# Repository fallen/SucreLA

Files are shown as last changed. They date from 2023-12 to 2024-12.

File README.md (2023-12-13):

# SucréLA

## Building

The project Python's dependencies are handled using Pipenv.
However, you must install [nextpnr-ecp5](https://github.com/YosysHQ/nextpnr) and [Yosys](https://github.com/YosysHQ/yosys) if you wish to build the
projet from source.

```
pipenv install --ignore-pipfile
pipenv run python3 ./sucrela.py --build
```

## Flashing the OrangeCrab

```
pipenv run python3 ./sucrela.py --load
```

## Runing simulation

```
pipenv run python3 ./sucrela.py --sim
```

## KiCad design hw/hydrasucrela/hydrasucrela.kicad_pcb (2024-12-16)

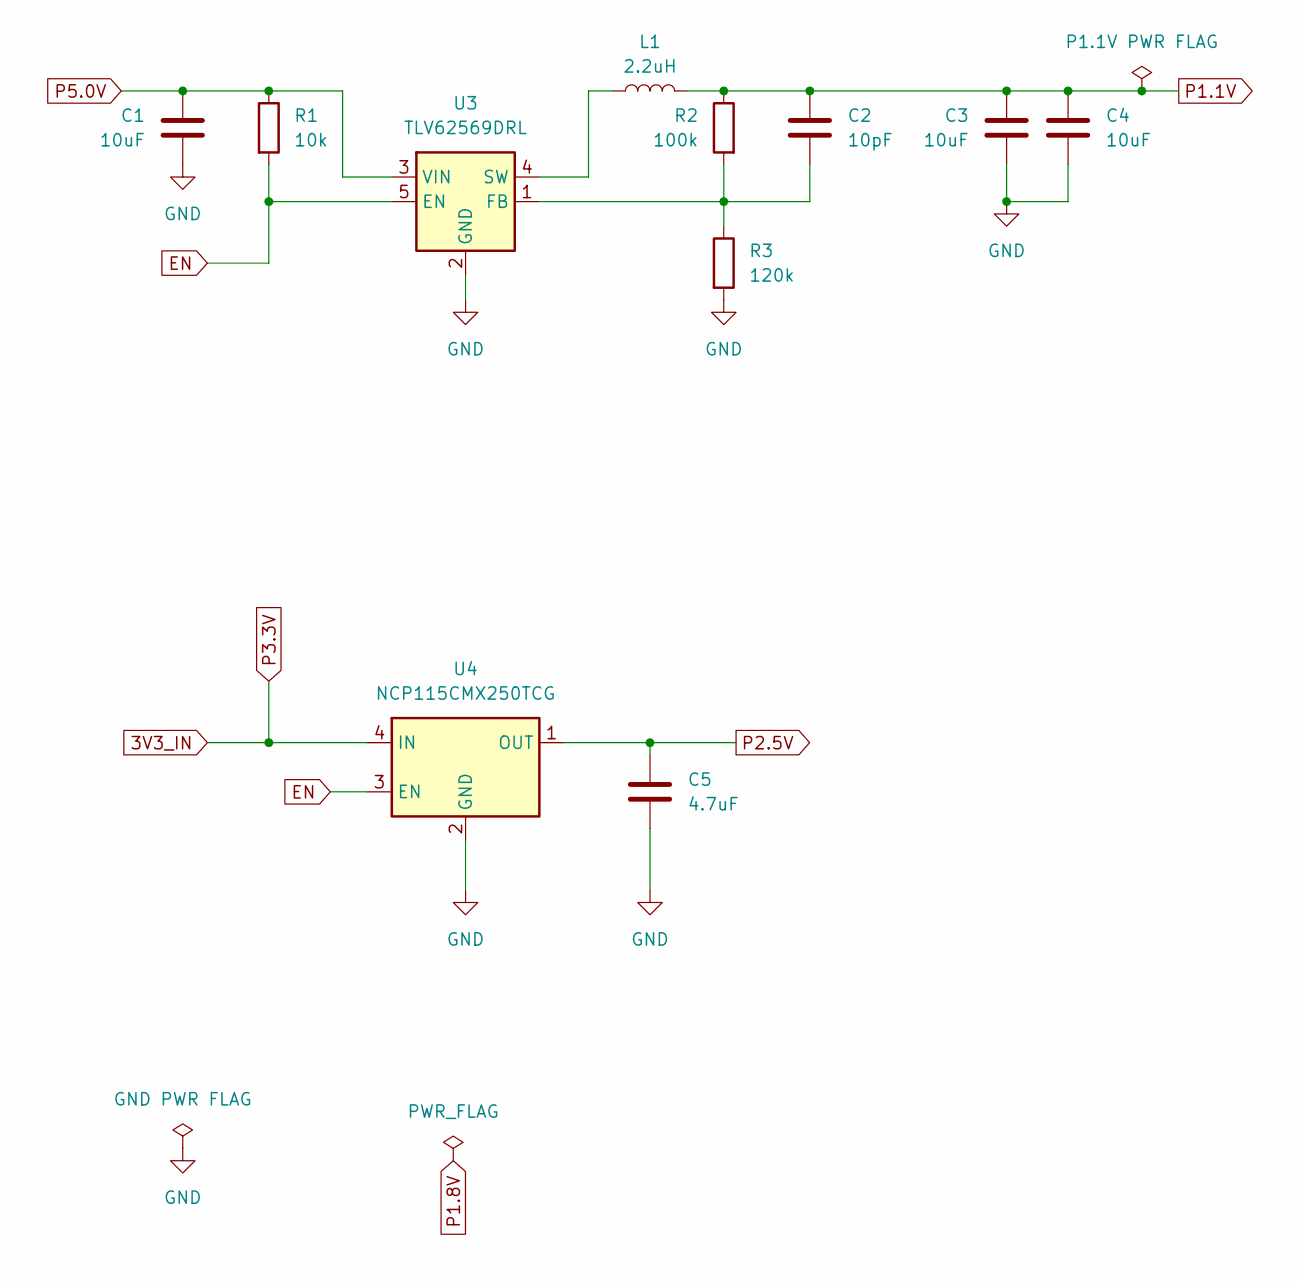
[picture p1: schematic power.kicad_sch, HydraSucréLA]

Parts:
C1, C3, C4: 10uF; C_0603_1608Metric_Pad1.08x0.95mm_HandSolder
C2: 10pF; C_0603_1608Metric_Pad1.08x0.95mm_HandSolder
C5: 4.7uF; C_0603_1608Metric_Pad1.08x0.95mm_HandSolder
L1: 2.2uH; L_0603_1608Metric_Pad1.05x0.95mm_HandSolder
R1: 10k; R_0603_1608Metric_Pad0.98x0.95mm_HandSolder
R2: 100k; R_0603_1608Metric_Pad0.98x0.95mm_HandSolder
R3: 120k; R_0603_1608Metric_Pad0.98x0.95mm_HandSolder
U3: TLV62569DRL; SOT-563
U4: NCP115CMX250TCG; OnSemi_XDFN4-1EP_1.0x1.0mm_EP0.52x0.52mm

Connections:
3V3_IN: U4.4 (IN); also elsewhere on the board
EN: R1.2, U3.5 (EN), U4.3 (EN)
GND: C1.2, C3.1, C4.1, C5.2, R3.2, U3.2 (GND), U4.2 (GND), U4.5 (GND); also elsewhere on the board
unnamed: C2.1, R2.2, R3.1, U3.1 (FB)
unnamed: L1.1, U3.4 (SW)
P1.1V: C2.2, C3.2, C4.2, L1.2, R2.1; also elsewhere on the board
P2.5V: C5.1, U4.1 (OUT); also elsewhere on the board
P5.0V: C1.1, R1.1, U3.3 (VIN); also elsewhere on the board

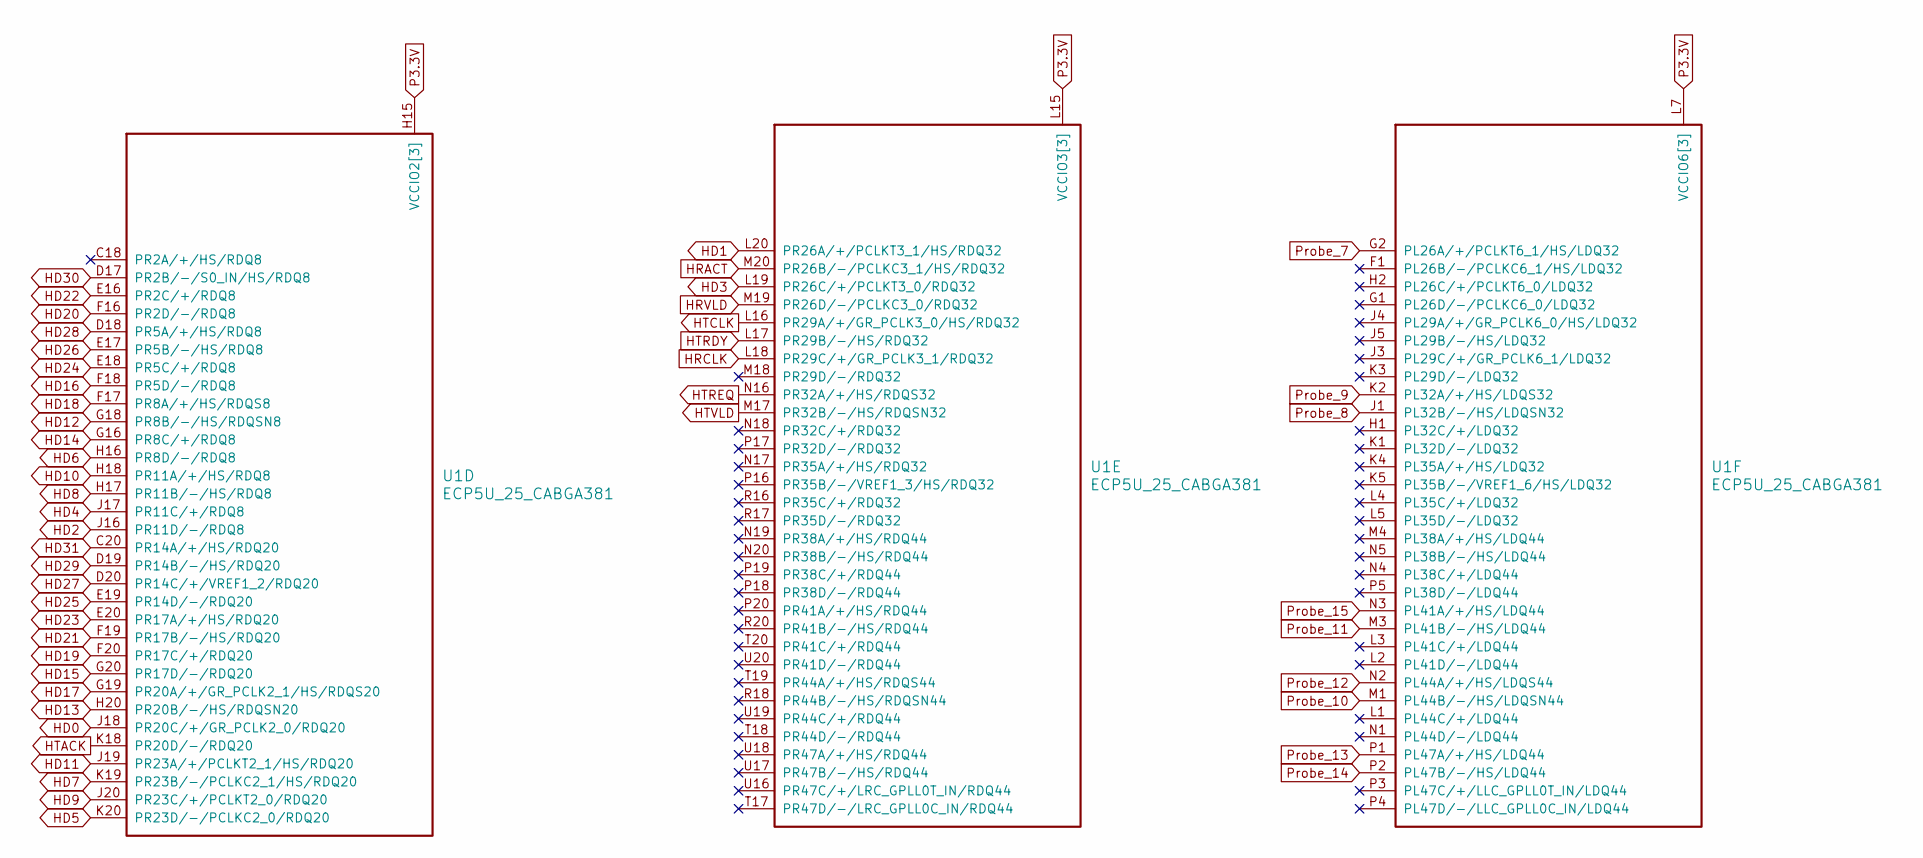
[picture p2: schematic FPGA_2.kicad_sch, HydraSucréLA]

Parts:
U1: ECP5U_25_CABGA381; Lattice_caBGA-381_17.0x17.0mm_Layout20x20_P0.8mm_Ball0.4mm_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

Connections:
3V3_IN: U1.H14 (VCCIO2[3]), U1.H15 (VCCIO2[3]), U1.J15 (VCCIO2[3]), U1.L6 (VCCIO6[3]), U1.L7 (VCCIO6[3]), U1.L14 (VCCIO3[3]), U1.L15 (VCCIO3[3]), U1.M6 (VCCIO6[3]), U1.M15 (VCCIO3[3]); also elsewhere on the board
HD0: U1.J18 (PR20C/+/GR_PCLK2_0/RDQ20); also elsewhere on the board
HD1: U1.L20 (PR26A/+/PCLKT3_1/HS/RDQ32); also elsewhere on the board
HD2: U1.J16 (PR11D/-/RDQ8); also elsewhere on the board
HD3: U1.L19 (PR26C/+/PCLKT3_0/RDQ32); also elsewhere on the board
HD4: U1.J17 (PR11C/+/RDQ8); also elsewhere on the board
HD5: U1.K20 (PR23D/-/PCLKC2_0/RDQ20); also elsewhere on the board
HD6: U1.H16 (PR8D/-/RDQ8); also elsewhere on the board
HD7: U1.K19 (PR23B/-/PCLKC2_1/HS/RDQ20); also elsewhere on the board
HD8: U1.H17 (PR11B/-/HS/RDQ8); also elsewhere on the board
HD9: U1.J20 (PR23C/+/PCLKT2_0/RDQ20); also elsewhere on the board
HD10: U1.H18 (PR11A/+/HS/RDQ8); also elsewhere on the board
HD11: U1.J19 (PR23A/+/PCLKT2_1/HS/RDQ20); also elsewhere on the board
HD12: U1.G18 (PR8B/-/HS/RDQSN8); also elsewhere on the board
HD13: U1.H20 (PR20B/-/HS/RDQSN20); also elsewhere on the board
HD14: U1.G16 (PR8C/+/RDQ8); also elsewhere on the board
HD15: U1.G20 (PR17D/-/RDQ20); also elsewhere on the board
HD16: U1.F18 (PR5D/-/RDQ8); also elsewhere on the board
HD17: U1.G19 (PR20A/+/GR_PCLK2_1/HS/RDQS20); also elsewhere on the board
HD18: U1.F17 (PR8A/+/HS/RDQS8); also elsewhere on the board
HD19: U1.F20 (PR17C/+/RDQ20); also elsewhere on the board
HD20: U1.F16 (PR2D/-/RDQ8); also elsewhere on the board
HD21: U1.F19 (PR17B/-/HS/RDQ20); also elsewhere on the board
HD22: U1.E16 (PR2C/+/RDQ8); also elsewhere on the board
HD23: U1.E20 (PR17A/+/HS/RDQ20); also elsewhere on the board
HD24: U1.E18 (PR5C/+/RDQ8); also elsewhere on the board
HD25: U1.E19 (PR14D/-/RDQ20); also elsewhere on the board
HD26: U1.E17 (PR5B/-/HS/RDQ8); also elsewhere on the board
HD27: U1.D20 (PR14C/+/VREF1_2/RDQ20); also elsewhere on the board
HD28: U1.D18 (PR5A/+/HS/RDQ8); also elsewhere on the board
HD29: U1.D19 (PR14B/-/HS/RDQ20); also elsewhere on the board
HD30: U1.D17 (PR2B/-/S0_IN/HS/RDQ8); also elsewhere on the board
HD31: U1.C20 (PR14A/+/HS/RDQ20); also elsewhere on the board
HRACT: U1.M20 (PR26B/-/PCLKC3_1/HS/RDQ32); also elsewhere on the board
HRCLK: U1.L18 (PR29C/+/GR_PCLK3_1/RDQ32); also elsewhere on the board
HRVLD: U1.M19 (PR26D/-/PCLKC3_0/RDQ32); also elsewhere on the board
HTACK: U1.K18 (PR20D/-/RDQ20); also elsewhere on the board
HTCLK: U1.L16 (PR29A/+/GR_PCLK3_0/HS/RDQ32); also elsewhere on the board
HTRDY: U1.L17 (PR29B/-/HS/RDQ32); also elsewhere on the board
HTREQ: U1.N16 (PR32A/+/HS/RDQS32); also elsewhere on the board
HTVLD: U1.M17 (PR32B/-/HS/RDQSN32); also elsewhere on the board
Probe_7: U1.G2 (PL26A/+/PCLKT6_1/HS/LDQ32); also elsewhere on the board
Probe_8: U1.J1 (PL32B/-/HS/LDQSN32); also elsewhere on the board
Probe_9: U1.K2 (PL32A/+/HS/LDQS32); also elsewhere on the board
Probe_10: U1.M1 (PL44B/-/HS/LDQSN44); also elsewhere on the board
Probe_11: U1.M3 (PL41B/-/HS/LDQ44); also elsewhere on the board
Probe_12: U1.N2 (PL44A/+/HS/LDQS44); also elsewhere on the board
Probe_13: U1.P1 (PL47A/+/HS/LDQ44); also elsewhere on the board
Probe_14: U1.P2 (PL47B/-/HS/LDQ44); also elsewhere on the board
Probe_15: U1.N3 (PL41A/+/HS/LDQ44); also elsewhere on the board

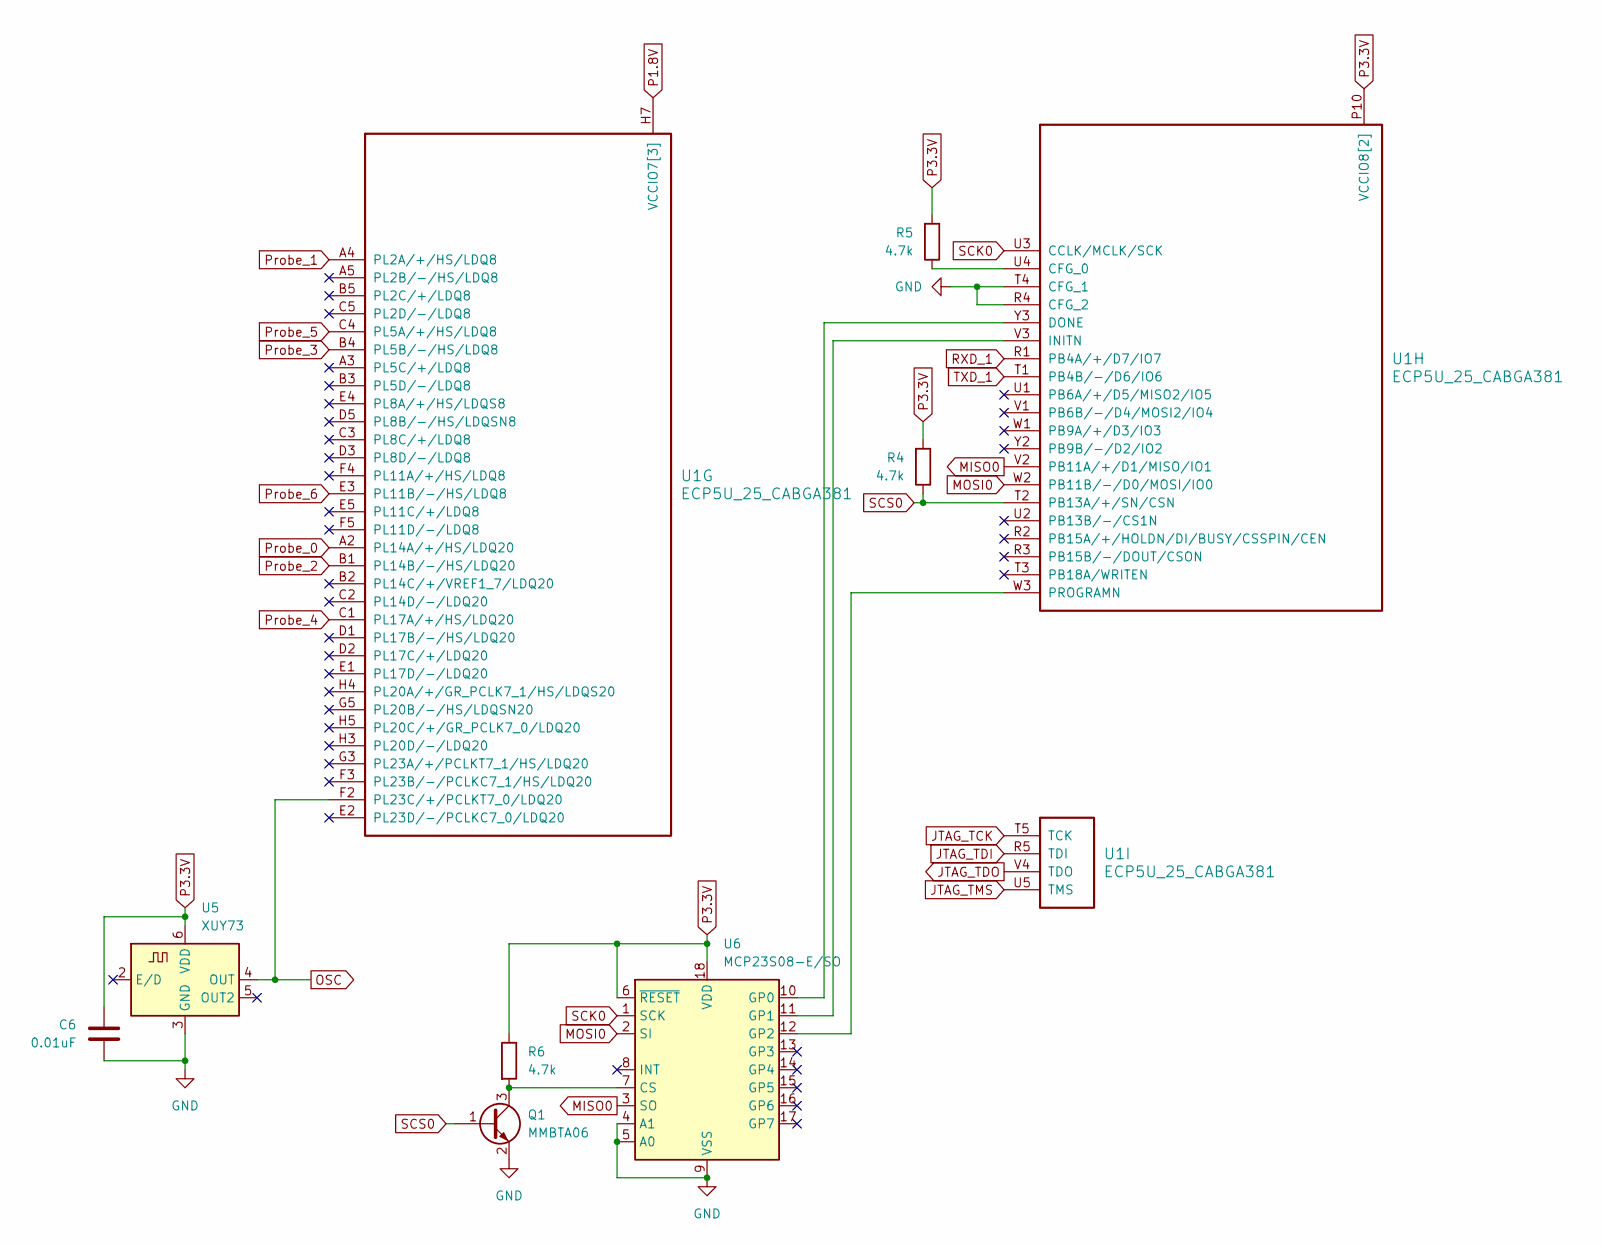
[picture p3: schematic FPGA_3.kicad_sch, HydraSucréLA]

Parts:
C6: 0.01uF; C_0603_1608Metric_Pad1.08x0.95mm_HandSolder
Q1: MMBTA06; SOT-23
R4, R5, R6: 4.7k; R_0603_1608Metric_Pad0.98x0.95mm_HandSolder
U1: ECP5U_25_CABGA381; Lattice_caBGA-381_17.0x17.0mm_Layout20x20_P0.8mm_Ball0.4mm_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
U5: XUY73; Oscillator_SMD_IDT_JU6-6_7.0x5.0mm_P2.54mm
U6: MCP23S08-E/SO; SOIC-18W_7.5x11.6mm_P1.27mm

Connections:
3V3_IN: C6.1, R4.2, R5.2, R6.1, U1.P9 (VCCIO8[2]), U1.P10 (VCCIO8[2]), U5.6 (VDD), U6.6 (~RESET), U6.18 (VDD); also elsewhere on the board
GND: C6.2, Q1.2 (E), U1.R4 (CFG_2), U1.T4 (CFG_1), U5.3 (GND), U6.4 (A1), U6.5 (A0), U6.9 (VSS); also elsewhere on the board
JTAG_TCK: U1.T5 (TCK); also elsewhere on the board
JTAG_TDI: U1.R5 (TDI); also elsewhere on the board
JTAG_TDO: U1.V4 (TDO); also elsewhere on the board
JTAG_TMS: U1.U5 (TMS); also elsewhere on the board
MISO0: U1.V2 (PB11A/+/D1/MISO/IO1), U6.3 (SO); also elsewhere on the board
MOSI0: U1.W2 (PB11B/-/D0/MOSI/IO0), U6.2 (SI); also elsewhere on the board
unnamed: Q1.3 (C), R6.2, U6.7 (CS)
unnamed: R5.1, U1.U4 (CFG_0)
unnamed: U1.Y3 (DONE), U6.10 (GP0)
unnamed: U1.V3 (INITN), U6.11 (GP1)
unnamed: U1.W3 (PROGRAMN), U6.12 (GP2)
OSC: U1.F2 (PL23C/+/PCLKT7_0/LDQ20), U5.4 (OUT)
P1.8V: U1.H6 (VCCIO7[3]), U1.H7 (VCCIO7[3]), U1.J6 (VCCIO7[3])
Probe_0: U1.A2 (PL14A/+/HS/LDQ20); also elsewhere on the board
Probe_1: U1.A4 (PL2A/+/HS/LDQ8); also elsewhere on the board
Probe_2: U1.B1 (PL14B/-/HS/LDQ20); also elsewhere on the board
Probe_3: U1.B4 (PL5B/-/HS/LDQ8); also elsewhere on the board
Probe_4: U1.C1 (PL17A/+/HS/LDQ20); also elsewhere on the board
Probe_5: U1.C4 (PL5A/+/HS/LDQ8); also elsewhere on the board
Probe_6: U1.E3 (PL11B/-/HS/LDQ8); also elsewhere on the board
RXD_1: U1.R1 (PB4A/+/D7/IO7); also elsewhere on the board
SCK0: U1.U3 (CCLK/MCLK/SCK), U6.1 (SCK); also elsewhere on the board
SCS0: Q1.1 (B), R4.1, U1.T2 (PB13A/+/SN/CSN); also elsewhere on the board
TXD_1: U1.T1 (PB4B/-/D6/IO6); also elsewhere on the board

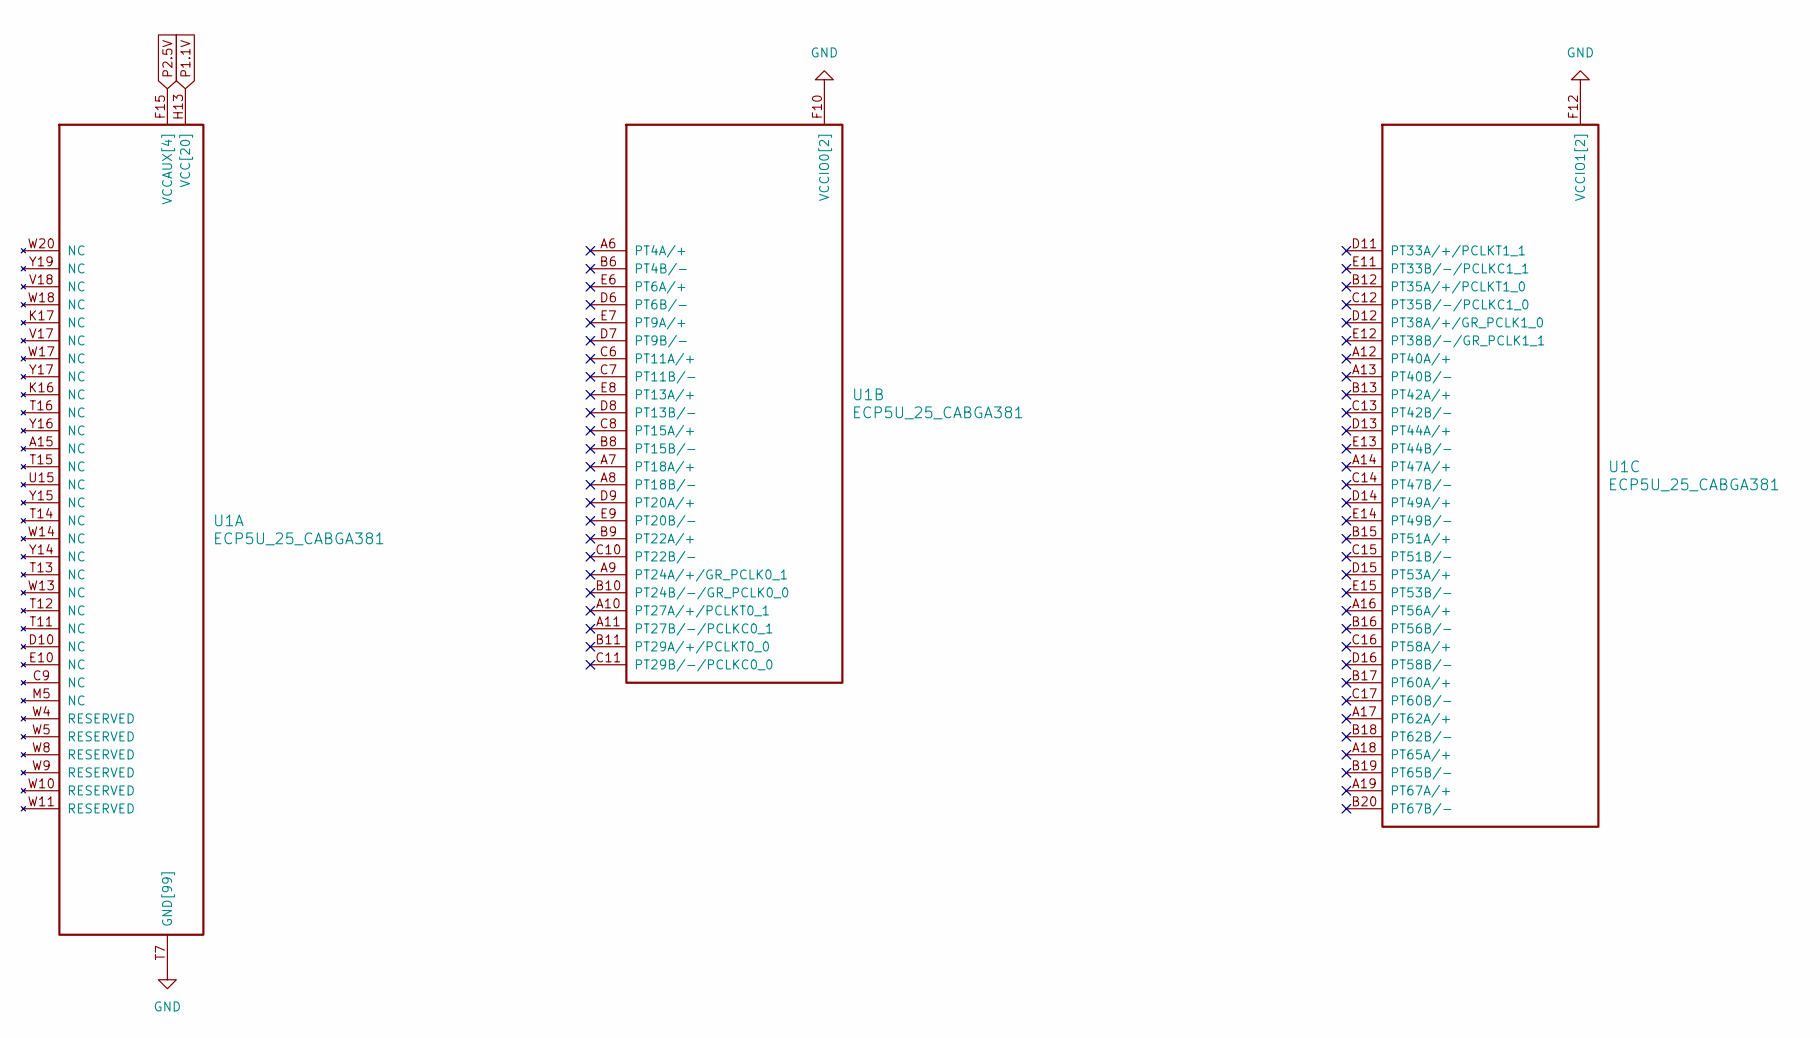
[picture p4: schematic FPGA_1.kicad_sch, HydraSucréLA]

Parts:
U1: ECP5U_25_CABGA381; Lattice_caBGA-381_17.0x17.0mm_Layout20x20_P0.8mm_Ball0.4mm_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

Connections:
GND: U1.B7 (GND[99]), U1.B14 (GND[99]), U1.C19 (GND[99]), U1.D4 (GND[99]), U1.F7 (GND[99]), U1.F8 (GND[99]), U1.F9 (VCCIO0[2]), U1.F10 (VCCIO0[2]), U1.F11 (VCCIO1[2]), U1.F12 (VCCIO1[2]), U1.F13 (GND[99]), U1.F14 (GND[99]), U1.G4 (GND[99]), U1.G6 (GND[99]), U1.G7 (GND[99]), U1.G8 (GND[99]), U1.G9 (GND[99]), U1.G10 (GND[99]), U1.G11 (GND[99]), U1.G12 (GND[99]), U1.G13 (GND[99]), U1.G14 (GND[99]), U1.G15 (GND[99]), U1.G17 (GND[99]), U1.H19 (GND[99]), U1.J2 (GND[99]), U1.J7 (GND[99]), U1.J9 (GND[99]), U1.J10 (GND[99]), U1.J11 (GND[99]), U1.J12 (GND[99]), U1.J14 (GND[99]), U1.K6 (GND[99]), U1.K7 (GND[99]), U1.K9 (GND[99]), U1.K10 (GND[99]), U1.K11 (GND[99]), U1.K12 (GND[99]), U1.K14 (GND[99]), U1.K15 (GND[99]), U1.L9 (GND[99]), U1.L10 (GND[99]), U1.L11 (GND[99]), U1.L12 (GND[99]), U1.M2 (GND[99]), U1.M7 (GND[99]), U1.M9 (GND[99]), U1.M10 (GND[99]), U1.M11 (GND[99]), U1.M12 (GND[99]), U1.M14 (GND[99]), U1.M16 (GND[99]), U1.N6 (GND[99]), U1.N7 (GND[99]), U1.N14 (GND[99]), U1.N15 (GND[99]), U1.P7 (GND[99]), U1.P8 (GND[99]), U1.P11 (GND[99]), U1.P12 (GND[99]), U1.P13 (GND[99]), U1.P14 (GND[99]), U1.R19 (GND[99]), U1.T6 (GND[99]), U1.T7 (GND[99]), U1.T8 (GND[99]), U1.T9 (GND[99]), U1.T10 (GND[99]), U1.U6 (GND[99]), U1.U7 (GND[99]), U1.U8 (GND[99]), U1.U9 (GND[99]), U1.U10 (GND[99]), U1.U11 (GND[99]), U1.U12 (GND[99]), U1.U13 (GND[99]), U1.U14 (GND[99]), U1.V5 (GND[99]), U1.V6 (GND[99]), U1.V7 (GND[99]), U1.V8 (GND[99]), U1.V9 (GND[99]), U1.V10 (GND[99]), U1.V11 (GND[99]), U1.V12 (GND[99]), U1.V13 (GND[99]), U1.V14 (GND[99]), U1.V15 (GND[99]), U1.V16 (GND[99]), U1.V19 (GND[99]), U1.V20 (GND[99]), U1.W6 (GND[99]), U1.W7 (GND[99]), U1.W12 (GND[99]), U1.W15 (GND[99]), U1.W16 (GND[99]), U1.W19 (GND[99]), U1.Y5 (GND[99]), U1.Y6 (GND[99]), U1.Y7 (GND[99]), U1.Y8 (GND[99]), U1.Y11 (GND[99]), U1.Y12 (GND[99]); also elsewhere on the board
P1.1V: U1.H8 (VCC[20]), U1.H9 (VCC[20]), U1.H10 (VCC[20]), U1.H11 (VCC[20]), U1.H12 (VCC[20]), U1.H13 (VCC[20]), U1.J8 (VCC[20]), U1.J13 (VCC[20]), U1.K8 (VCC[20]), U1.K13 (VCC[20]), U1.L8 (VCC[20]), U1.L13 (VCC[20]), U1.M8 (VCC[20]), U1.M13 (VCC[20]), U1.N8 (VCC[20]), U1.N9 (VCC[20]), U1.N10 (VCC[20]), U1.N11 (VCC[20]), U1.N12 (VCC[20]), U1.N13 (VCC[20]); also elsewhere on the board
P2.5V: U1.F6 (VCCAUX[4]), U1.F15 (VCCAUX[4]), U1.P6 (VCCAUX[4]), U1.P15 (VCCAUX[4]); also elsewhere on the board

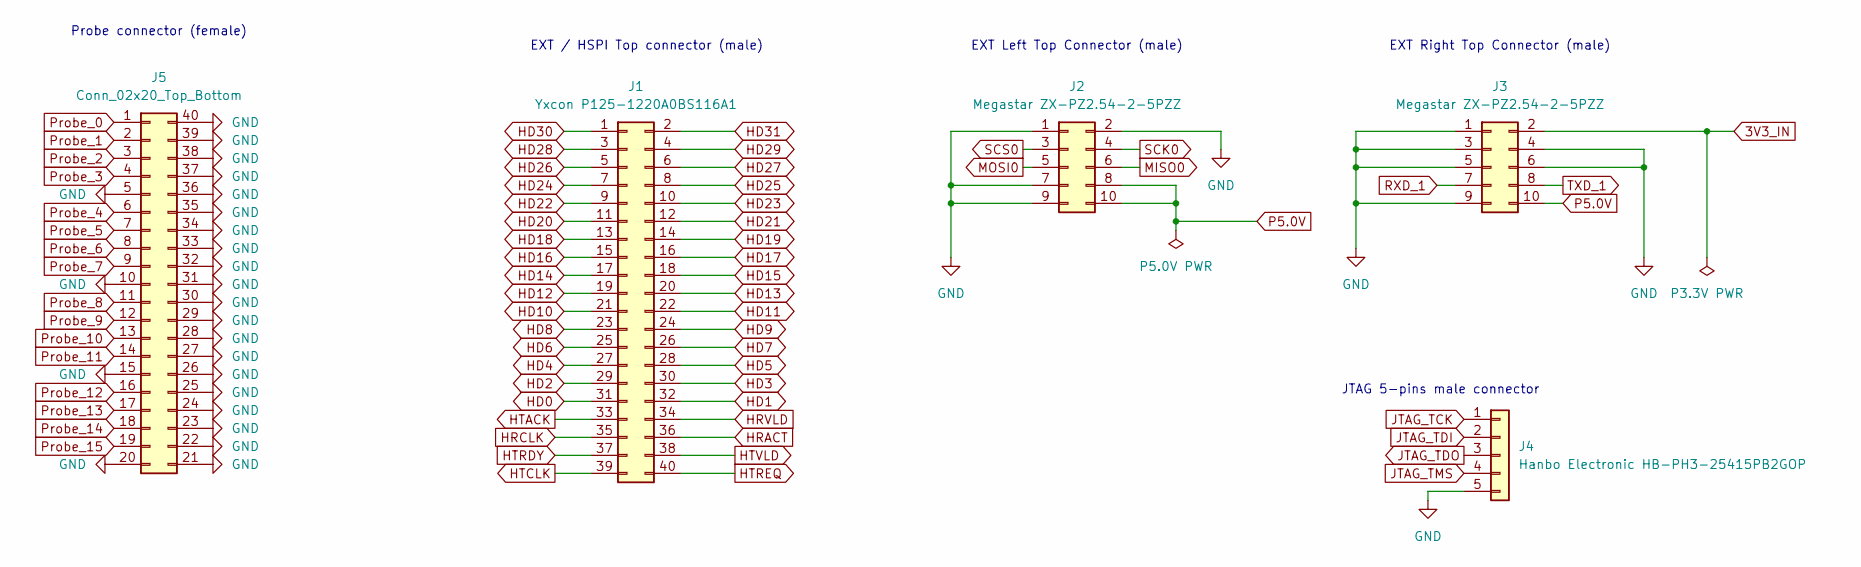
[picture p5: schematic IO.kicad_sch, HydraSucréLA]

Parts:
J1: Yxcon P125-1220A0BS116A1; PinHeader_2x20_P2.54mm_Vertical
J2, J3: Megastar ZX-PZ2.54-2-5PZZ; PinHeader_2x05_P2.54mm_Vertical
J4: Hanbo Electronic HB-PH3-25415PB2GOP; PinSocket_1x05_P2.54mm_Vertical
J5: Conn_02x20_Top_Bottom; probe_connector

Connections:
3V3_IN: J3.2; also elsewhere on the board
GND: J2.1, J2.2, J2.7, J2.9, J3.1, J3.3, J3.4, J3.5, J3.6, J3.9, J4.5, J5.5, J5.10, J5.15, J5.20, J5.21, J5.22, J5.23, J5.24, J5.25, J5.26, J5.27, J5.28, J5.29, J5.30, J5.31, J5.32, J5.33, J5.34, J5.35, J5.36, J5.37, J5.38, J5.39, J5.40; also elsewhere on the board
HD0: J1.31; also elsewhere on the board
HD1: J1.32; also elsewhere on the board
HD2: J1.29; also elsewhere on the board
HD3: J1.30; also elsewhere on the board
HD4: J1.27; also elsewhere on the board
HD5: J1.28; also elsewhere on the board
HD6: J1.25; also elsewhere on the board
HD7: J1.26; also elsewhere on the board
HD8: J1.23; also elsewhere on the board
HD9: J1.24; also elsewhere on the board
HD10: J1.21; also elsewhere on the board
HD11: J1.22; also elsewhere on the board
HD12: J1.19; also elsewhere on the board
HD13: J1.20; also elsewhere on the board
HD14: J1.17; also elsewhere on the board
HD15: J1.18; also elsewhere on the board
HD16: J1.15; also elsewhere on the board
HD17: J1.16; also elsewhere on the board
HD18: J1.13; also elsewhere on the board
HD19: J1.14; also elsewhere on the board
HD20: J1.11; also elsewhere on the board
HD21: J1.12; also elsewhere on the board
HD22: J1.9; also elsewhere on the board
HD23: J1.10; also elsewhere on the board
HD24: J1.7; also elsewhere on the board
HD25: J1.8; also elsewhere on the board
HD26: J1.5; also elsewhere on the board
HD27: J1.6; also elsewhere on the board
HD28: J1.3; also elsewhere on the board
HD29: J1.4; also elsewhere on the board
HD30: J1.1; also elsewhere on the board
HD31: J1.2; also elsewhere on the board
HRACT: J1.36; also elsewhere on the board
HRCLK: J1.35; also elsewhere on the board
HRVLD: J1.34; also elsewhere on the board
HTACK: J1.33; also elsewhere on the board
HTCLK: J1.39; also elsewhere on the board
HTRDY: J1.37; also elsewhere on the board
HTREQ: J1.40; also elsewhere on the board
HTVLD: J1.38; also elsewhere on the board
JTAG_TCK: J4.1; also elsewhere on the board
JTAG_TDI: J4.2; also elsewhere on the board
JTAG_TDO: J4.3; also elsewhere on the board
JTAG_TMS: J4.4; also elsewhere on the board
MISO0: J2.6; also elsewhere on the board
MOSI0: J2.5; also elsewhere on the board
P5.0V: J2.8, J2.10, J3.10; also elsewhere on the board
Probe_0: J5.1; also elsewhere on the board
Probe_1: J5.2; also elsewhere on the board
Probe_2: J5.3; also elsewhere on the board
Probe_3: J5.4; also elsewhere on the board
Probe_4: J5.6; also elsewhere on the board
Probe_5: J5.7; also elsewhere on the board
Probe_6: J5.8; also elsewhere on the board
Probe_7: J5.9; also elsewhere on the board
Probe_8: J5.11; also elsewhere on the board
Probe_9: J5.12; also elsewhere on the board
Probe_10: J5.13; also elsewhere on the board
Probe_11: J5.14; also elsewhere on the board
Probe_12: J5.16; also elsewhere on the board
Probe_13: J5.17; also elsewhere on the board
Probe_14: J5.18; also elsewhere on the board
Probe_15: J5.19; also elsewhere on the board
RXD_1: J3.7; also elsewhere on the board
SCK0: J2.4; also elsewhere on the board
SCS0: J2.3; also elsewhere on the board
TXD_1: J3.8; also elsewhere on the board

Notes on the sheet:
Probe connector (female)
EXT Right Top Connector (male)
EXT / HSPI Top connector (male)
JTAG 5-pins male connector
EXT Left Top Connector (male)

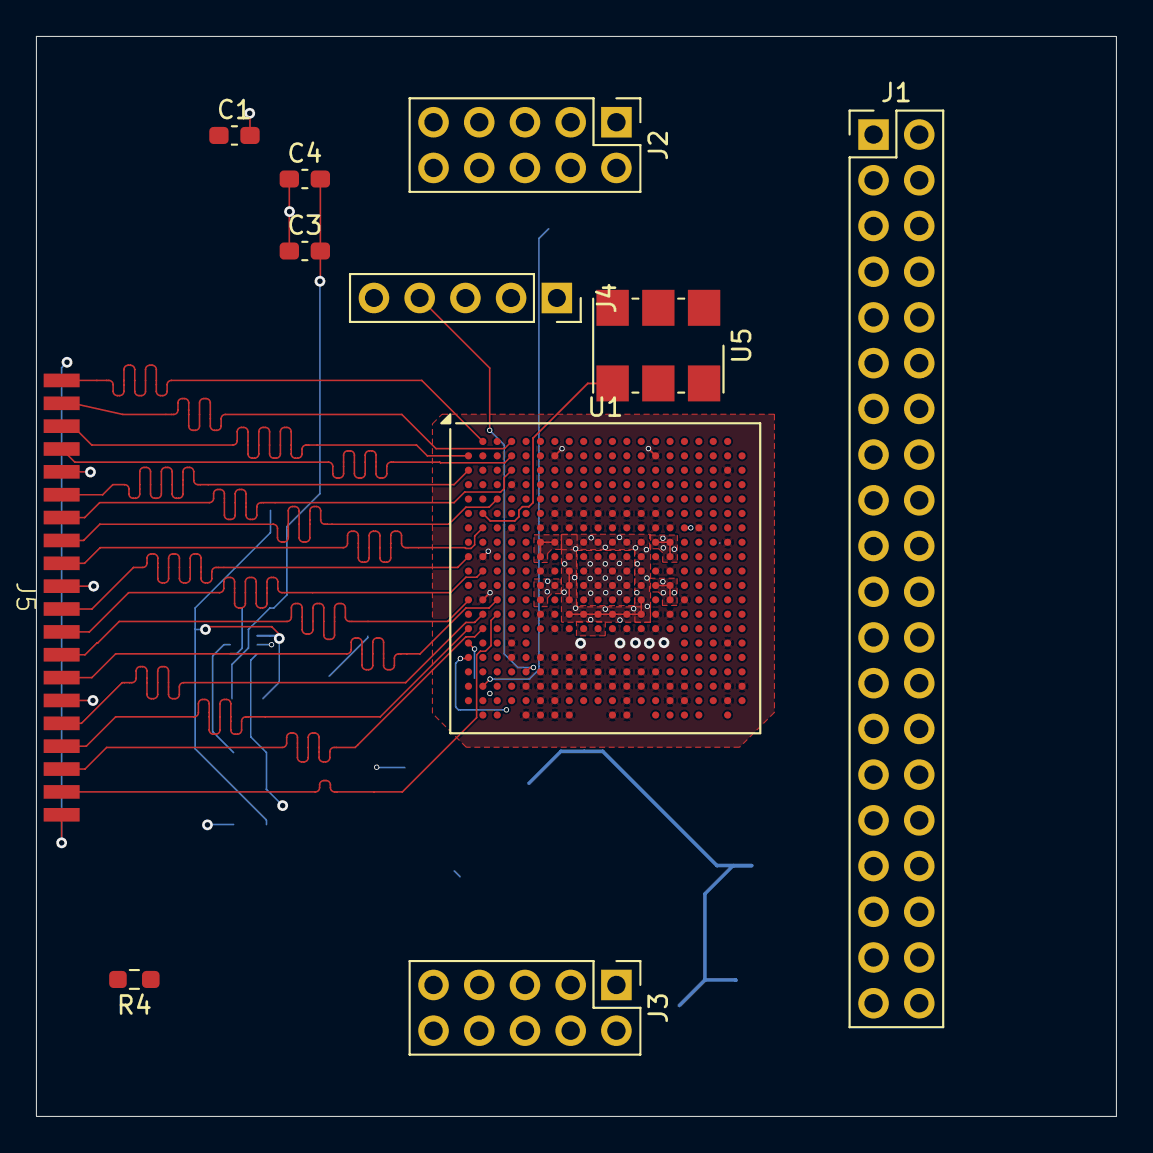
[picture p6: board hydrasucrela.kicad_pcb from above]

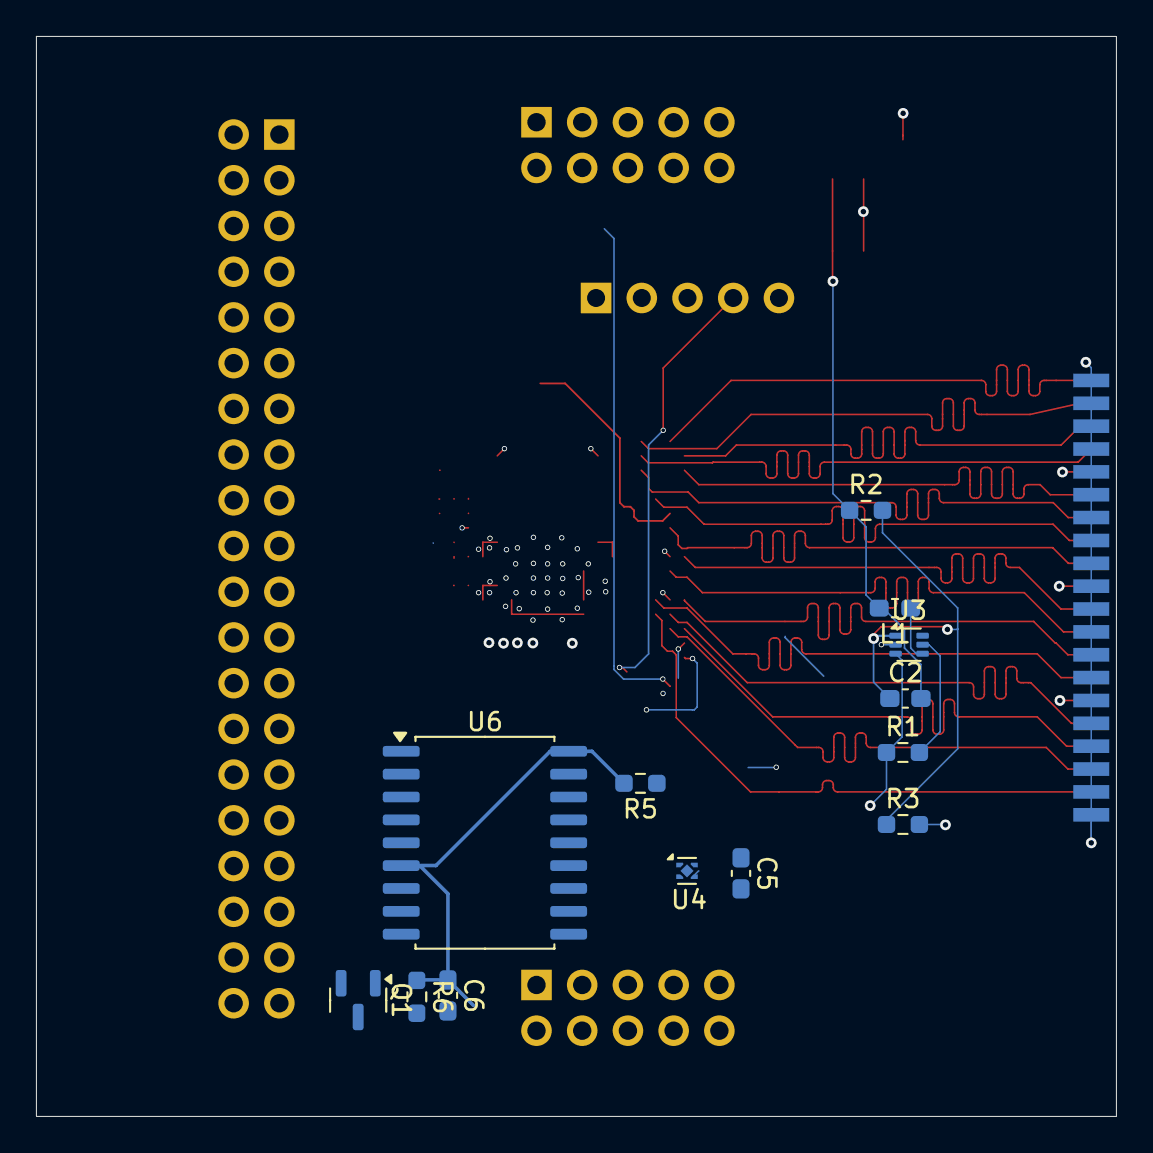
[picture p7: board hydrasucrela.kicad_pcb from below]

Board: 4 copper layers, 60.0 x 60.0 mm, 24 parts (13 on the bottom side), 81 nets.

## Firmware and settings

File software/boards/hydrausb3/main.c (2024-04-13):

#include <stdint.h>
#include <stdio.h>
#include <string.h>
#include <stdlib.h>

/* System clock and HSPI freq : 120 MHz */
#define FREQ_SYS (120000000)

#include "core_riscv.h"
#include "CH56x_bsp.h"
#include "CH56x_uart.h"
#include "CH56x_common.h"

#include "config.h"
#include "uartbone.h"
#include "csr.h" // for FPGA SoC CSR register addresses

#include "CH56x_usb30_devbulk.h"
#include "CH56x_usb20_devbulk.h"
#include "CH56x_usb30_devbulk_LIB.h"
#include "CH56x_usb_devbulk_desc_cmd.h"

#include "hydrausb3_usb_devbulk_vid_pid.h"

#define RISCV_FENCE(p, s) \
	__asm__ __volatile__ ("fence " #p "," #s : : : "memory")

/* These barriers need to enforce ordering on both devices or memory. */
#define mb()		RISCV_FENCE(iorw,iorw)
#define rmb()		RISCV_FENCE(ir,ir)
#define wmb()		RISCV_FENCE(ow,ow)

__attribute__((aligned(16))) volatile uint8_t HSPI_RX_Addr0[HSPI_RX_DMA_LENGTH] __attribute__((section(".DMADATA")));
__attribute__((aligned(16))) volatile uint8_t HSPI_RX_Addr1[HSPI_RX_DMA_LENGTH] __attribute__((section(".DMADATA")));

/* Shared variables */
volatile int HSPI_TX_End_Flag; // Send completion flag
volatile int HSPI_RX_End_Flag; // Receive completion flag
volatile int HSPI_RX_End_Err; // 0=No Error else >0 Error code

/* FLASH_ROMA Read Unique ID (8bytes/64bits) */
#define FLASH_ROMA_UID_ADDR (0x77fe4)
usb_descriptor_serial_number_t unique_id;

/* USB VID PID */
usb_descriptor_usb_vid_pid_t vid_pid =
{
	.vid = USB_VID,
	.pid = USB_PID
};

void uartbone_ch56x_init(struct uartbone_ctx *ctx, int uart_num, int baudrate, int addr_width);

volatile int usb_cmd_rxed = 0;
volatile uint8_t usb_cmd[11];
volatile uint8_t usb_cmd_len;
extern volatile int EP1_to_be_sent;
volatile int ep1_out_nack = 0;
volatile unsigned int hspi_rx_packets = 0;
volatile unsigned int hspi_first_error_packet = -1;

static void USB_init(void) {
	R32_USB_CONTROL = 0;
	PFIC_EnableIRQ(USBSS_IRQn);
	PFIC_EnableIRQ(LINK_IRQn);
	PFIC_EnableIRQ(TMR0_IRQn);
	R8_TMR0_INTER_EN = RB_TMR_IE_CYC_END;
	TMR0_TimerInit(67000000); // USB3.0 connection failure timeout about 0.56 seconds

	/* USB Descriptor set String Serial Number with CH569 Unique ID */
	usb_descriptor_set_string_serial_number(&unique_id);

	/* USB Descriptor set USB VID/PID */
	usb_descriptor_set_usb_vid_pid(&vid_pid);

	/* USB3.0 initialization, make sure that the two USB3.0 interrupts are enabled before initialization */
	USB30D_init(ENABLE);
}

#undef DEBUG

int main(void) {
	struct uartbone_ctx ctx;
	int i = 0;
	char c;
	volatile uint8_t *hspi_rxed_bytes = (volatile uint8_t *)HSPI_RX_Addr0;
	bool print_done = false;

	bsp_gpio_init();
	bsp_init(FREQ_SYS);
	memset(&unique_id, 0, sizeof(unique_id));
	FLASH_ROMA_READ(FLASH_ROMA_UID_ADDR, (uint32_t*)&unique_id, sizeof(unique_id));
	UART1_init(UART1_BAUD, FREQ_SYS);
	UART3_init(UART3_BAUD, FREQ_SYS);

	printf("\n\r");
	printf("###########################\n\r");
	printf("# SucreLA fw starting up! #\n\r");
	printf("###########################\n\r\n\r");

	printf("board: HydraUSB3\n\r");
	printf("USB init...");
	USB_init();
	printf("done\n\r");
	uartbone_ch56x_init(&ctx, 3, 115200, 4);
	printf("uartbone: initialized on UART3\n\r");

	printf("Preparing HSPI RX interface...\n\r");
	memset(HSPI_RX_Addr0, '\0', HSPI_RX_DMA_LENGTH);
	memset(HSPI_RX_Addr1, '\0', HSPI_RX_DMA_LENGTH);
	HSPI_RX_End_Flag = 0;  // Receive completion flag
	HSPI_RX_End_Err = 0; // 0=No Error else >0 Error code
	HSPI_DoubleDMA_Init(HSPI_DEVICE, HSPI_DATA_WIDTH, (unsigned long int)HSPI_RX_Addr0, (unsigned long int)HSPI_RX_Addr1, 0);
    R8_HSPI_RX_SC = 0;

	while (1) { // infinite loop to handle uartbone over USB protocole
		if (usb_cmd_rxed) {
			mb();
#ifdef DEBUG
			printf("usb rx!\n\r");
#endif
			switch (usb_cmd[0]) {
				case 'w': {
#ifdef DEBUG
					printf("uart sending: \n\r");
					for (i = 2; i < usb_cmd_len+2; i++)
						printf("%02x ", usb_cmd[i]);
					printf("\n\r");
#endif
					UART3_SendString(&usb_cmd[2], usb_cmd_len);
					usb_cmd_len = 0;
					break;
				}
				case 'r': {
					UART3_Recv(usb_cmd, usb_cmd_len);
#ifdef DEBUG
					printf("uart rx'ed: \n\r");
					for (i = 0; i < usb_cmd_len; i++)
						printf("%02x ", usb_cmd[i]);
					printf("\n\r");
#endif
					memcpy(endp1Tbuff, usb_cmd, usb_cmd_len);
					mb();
					EP1_to_be_sent = usb_cmd_len;
					USB30_IN_set(ENDP_1, ENABLE, ACK, 1, usb_cmd_len); // Set the endpoint to be able to send 1 packet
					USB30_send_ERDY(ENDP_1 | IN, 1); // Notify the host we are ready to receive 1 IN packet
					usb_cmd_len = 0;
					break;
				}
				default: {
					printf("buggy usb cmd: \n\r");
					for (i = 0; i < usb_cmd_len + 1; i++)
						printf("%02x ", usb_cmd[i]);
					printf("\n\r");
				}
			}
			usb_cmd_rxed = 0; // command completed, let's prepare for the next one.
			USB30_OUT_set(ENDP_1, ACK, 0); // Set EP1 to ACK next OUT packet, we can now receive a new command
			USB30_send_ERDY(ENDP_1 | OUT, 1); // Notify the host we are ready to receive 1 OUT packet
		}

        if (HSPI_RX_End_Flag) {
            if (!(hspi_rx_packets % 100))
              printf("HSPI received %d packets!\n\r", hspi_rx_packets);
            HSPI_RX_End_Flag = 0;
        }

        if (HSPI_RX_End_Err && (!print_done)) {
            int start = 0;
            bool error_printed = false;
            uint8_t prev;
            printf("HSPI received %d packets!\n\r", hspi_rx_packets);
            if (HSPI_RX_End_Err) {
                if (HSPI_RX_End_Err & RB_HSPI_CRC_ERR)
                    printf("HSPI CRC error\n\r");
                printf("first error packet was num #%d\n\r", hspi_first_error_packet);
            }
            bsp_wait_us_delay(1);
            printf("Packet 0: \n\r");
            while (hspi_rxed_bytes[start] == 0) {
                printf("%02x ", hspi_rxed_bytes[start]);
                start++;
            }
            prev = hspi_rxed_bytes[start] - 1;
            for (i = start; i < 4096 - start; i++) {
                if (!(i % 50))
                    printf("\n\r");
                printf("%02x ", hspi_rxed_bytes[i]);
                prev = hspi_rxed_bytes[i];
	        }
	        printf("\n\r");
            printf("RX0 LEN = %08x RX1 LEN = %08x\n\r", R16_HSPI_RX_LEN0, R16_HSPI_RX_LEN1);
	        printf("UDF0: %08x UDF1: %08x\n\r", R32_HSPI_UDF0, R32_HSPI_UDF1);
	        printf("RX NUM seq %02x\n\r", R8_HSPI_RX_SC);
            printf("Packet 1: \n\r");
            hspi_rxed_bytes = HSPI_RX_Addr1;
            start = 0;
            while (hspi_rxed_bytes[start] == 0) {
                printf("%02x ", hspi_rxed_bytes[start]);
                start++;
            }
            prev = hspi_rxed_bytes[start] - 1;
            for (i = start; i < 4096 - start; i++) {
                if (!(i % 50))
                    printf("\n\r");
                printf("%02x ", hspi_rxed_bytes[i]);
                prev = hspi_rxed_bytes[i];
	        }
            printf("\n\r");
            printf("RX0 LEN = %08x RX1 LEN = %08x\n\r", R16_HSPI_RX_LEN0, R16_HSPI_RX_LEN1);
	        printf("UDF0: %08x UDF1: %08x\n\r", R32_HSPI_UDF0, R32_HSPI_UDF1);
	        printf("RX NUM seq %02x\n\r", R8_HSPI_RX_SC);
            HSPI_RX_End_Err = 0;
            HSPI_RX_End_Flag = 0;
            print_done = true;
        }
	}

	return 0;
}

void HSPI_IRQHandler_ReInitRX(void)
{
	R32_HSPI_RX_ADDR0 = (unsigned long int)HSPI_RX_Addr0;
	R32_HSPI_RX_ADDR1 = (unsigned long int)HSPI_RX_Addr1;
}

__attribute__((interrupt("WCH-Interrupt-fast"))) void HSPI_IRQHandler(void)
{
	if (R8_HSPI_INT_FLAG & RB_HSPI_IF_R_DONE) // Single packet reception completed
	{
	    bool error = false;
		R8_HSPI_INT_FLAG = RB_HSPI_IF_R_DONE;  // Clear Interrupt
        hspi_rx_packets++;
        if (R8_HSPI_RX_SC & 0xf)
                R32_HSPI_RX_ADDR0 = (unsigned long int)HSPI_RX_Addr0;
        else
                R32_HSPI_RX_ADDR1 = (unsigned long int)HSPI_RX_Addr1;

		HSPI_RX_End_Flag = 1;
        if(R8_HSPI_RTX_STATUS & RB_HSPI_CRC_ERR) {
            HSPI_RX_End_Err |= RB_HSPI_CRC_ERR;
            error = true;
        }
        if(R8_HSPI_INT_FLAG & RB_HSPI_IF_FIFO_OV) {
            error = true;
            printf("HSPI FIFO overflow!\n\r");
            R8_HSPI_INT_FLAG = RB_HSPI_IF_FIFO_OV;
        }
        if (R8_HSPI_RTX_STATUS & RB_HSPI_NUM_MIS) {
            error = true;
            printf("HSPI seq num mismatch\n\r");
            HSPI_RX_End_Err |= RB_HSPI_NUM_MIS;
        }
        if (error) {
            printf("ERROR!!!\n\r");
            if (hspi_first_error_packet == -1)
                hspi_first_error_packet = hspi_rx_packets;
            return;
        }
        USB30_IN_set(ENDP_2, ENABLE, ACK, DEF_ENDP2_IN_BURST_LEVEL, 1024); // Able to send 4x 1024-bytes packets
        USB30_send_ERDY(ENDP_2 | IN, DEF_ENDP2_IN_BURST_LEVEL); // Tell Host we can accept EP2 IN packets
	}
}

__attribute__((interrupt("WCH-Interrupt-fast"))) void HardFault_Handler(void)
{
	printf("HardFault\n");
	printf(" SP=0x%08X\n", __get_SP());
	printf(" MIE=0x%08X\n", __get_MIE());
	printf(" MSTATUS=0x%08X\n", __get_MSTATUS());
	printf(" MCAUSE=0x%08X\n", __get_MCAUSE());
	bsp_wait_ms_delay(1);
}

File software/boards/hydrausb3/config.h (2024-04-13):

#ifndef _CONFIG_H_
#define _CONFIG_H_

/* UARTs settings */
#define UART1_BAUD 115200
#define UART3_BAUD 115200

/* HSPI Data width : 8 bits */
#define HSPI_DATA_WIDTH 0

#define HSPI_RX_DMA_LENGTH   4096

extern __attribute__((aligned(16))) volatile uint8_t HSPI_RX_Addr0[HSPI_RX_DMA_LENGTH] __attribute__((section(".DMADATA")));
extern __attribute__((aligned(16))) volatile uint8_t HSPI_RX_Addr1[HSPI_RX_DMA_LENGTH] __attribute__((section(".DMADATA")));

#endif

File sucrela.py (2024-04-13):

#!/usr/bin/env python3

from migen import *

from litex_boards.platforms.gsd_orangecrab import Platform, feather_serial
from litex_boards.targets.gsd_orangecrab import BaseSoC
from litex.build.generic_platform import *
from litex.soc.integration.builder import *

from litescope import LiteScopeAnalyzer

from modules.la import LA, LATest

feather_gpio = [
    ("gpios", 0, Pins("GPIO:2 GPIO:3 GPIO:5 GPIO:6"), IOStandard("LVCMOS33")  # C10 C9 B10 B9 aka SDA SCL 5 6
    )
]

feather_hspi = [
    ("hspi", 0,
     Subsignal("clk", Pins("GPIO:9"), IOStandard("LVCMOS33")),  # C8 aka 9
     Subsignal("req", Pins("GPIO:10"), IOStandard("LVCMOS33")),  # B8 aka 10
     Subsignal("ready", Pins("GPIO:11"), IOStandard("LVCMOS33")),  # A8 aka 11
     Subsignal("valid", Pins("GPIO:12"), IOStandard("LVCMOS33")),  # H2 aka 12
     Subsignal("hd", Pins("GPIO:13 GPIO:14 GPIO:15 GPIO:16 GPIO:18 GPIO:19 GPIO:20 GPIO:21"),
               IOStandard("LVCMOS33")),  # J2 N15 R17 N16 L4 N3 N4 H4 aka 13 MISO SCK MOSI A0 A1 A2 A3
     Subsignal("hract", Pins("GPIO:22"), IOStandard("LVCMOS33")),  # G4 aka A4
     Subsignal("htack", Pins("GPIO:23"), IOStandard("LVCMOS33")),  # T17 aka A5
    )
]


class LASoC(BaseSoC):
    def __init__(self, sys_clk_freq=48e6, **kwargs):
        BaseSoC.__init__(self, sys_clk_freq=sys_clk_freq,
                         with_led_chaser=True, **kwargs)

        self.cd_hspi = ClockDomain()
        self.platform.add_extension(feather_serial)
        self.platform.add_extension(feather_gpio)
        self.platform.add_extension(feather_hspi)
        self.add_uartbone()
        ios = self.platform.request("gpios")
        hspi_pads = self.platform.request("hspi")
        self.crg.pll.create_clkout(self.cd_hspi, 4e6)  # create 4 MHz clock for HSPI

        self.submodules.la = LA(ios, hspi_pads, depth=4096, clock_domain="hspi", samplerate=4e6,
                                testing=kwargs['testing'])

        if kwargs['testing']:
            analyzer_signals = [hspi_pads.req, hspi_pads.ready, hspi_pads.valid, hspi_pads.hract, hspi_pads.htack,
                                self.la.hspi_tx.hd.o, self.la.hspi_tx.hd.oe, self.cd_hspi.clk,
                                self.la.hspi_tx.remaining_packets]
            self.submodules.analyzer = LiteScopeAnalyzer(analyzer_signals,
                                                         depth=0x10000,
                                                         clock_domain="sys",
                                                         samplerate=sys_clk_freq,
                                                         csr_csv="analyzer.csv",
                                                         trigger_depth=64
                                                         )


def main():
    from litex.build.parser import LiteXArgumentParser
    parser = LiteXArgumentParser(platform=Platform, description="SucreLA on OrangeCrab.")
    parser.add_target_argument("--sys-clk-freq",    default=48e6, type=float, help="System clock frequency.")
    parser.add_target_argument("--revision",        default="0.2",            help="Board Revision (0.1 or 0.2).")
    parser.add_target_argument("--device",          default="85F",            help="ECP5 device (25F, 45F or 85F).")
    parser.add_target_argument("--sdram-device",    default="MT41K64M16",     help="SDRAM device (MT41K64M16, MT41K128M16, MT41K256M16 or MT41K512M16).")
    parser.add_target_argument("--sim",             action="store_true", help="run LA simulation testsuite")
    parser.add_target_argument("--testing",         action="store_true", help="run LA with testing sample data")
    parser.set_defaults(no_uart=True, cpu_type="None")
    args = parser.parse_args()

    if args.sim:
        LATest(stop_via="hspi")
        LATest(stop_via="storage")
        LATest()
        exit(0)

    soc = LASoC(sys_clk_freq=args.sys_clk_freq,
                revision=args.revision,
                device=args.device,
                sdram_device=args.sdram_device,
                testing=args.testing,
                **parser.soc_argdict)

    builder = Builder(soc, **parser.builder_argdict)
    if args.build:
        builder.build(**parser.toolchain_argdict)

    if args.load:
        prog = soc.platform.create_programmer()
        prog.load_bitstream(builder.get_bitstream_filename(mode="sram"))


if __name__ == "__main__":
    main()

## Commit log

2023-12-24 Add uartbone client for Linux platform
2023-12-27 uartbone: add -h arg and compile+run it in CI
    -h prints usage/help and returns 0 (success).
    In CI so far we just compile the Linux CLI and runs it with -h
2024-01-09 uartbone: fix print_usage()
2024-01-09 sucrela: refactor pin names and make ECP5 85F the default target
2024-03-03 uartbone: put linux specific code out of uartbone.c
    To allow compiling uartbone.c with a bare-metal RISC-V toolchain.
2024-03-03 uartbone: define endianness functions for xpack risc-v newlib nano based toolchain
2024-03-03 Add basic fw for hydrausb3
    HydraUSB3 board is used to prototype SucreLA
    Eventually a board featuring an ECP5 FPGA and a WCH569
    microcontroller will be designed.
    For now, let's use OrangeCrab FPGA board connected to
    HydraUSB3.
2024-03-04 fw: fix warning about implicite abort() declaration
    [uartbone.c]
2024-03-11 uartbone: use SendString instead of SendByte
    Because the latter checks if the TX FIFO is full before
    writing to the uart tx register.
2024-03-11 SoC: add comments to avoid back and forth with pinout/schematics pages
    [sucrela.py]
2024-03-11 SoC: pass correct arguments from cmdline to SoC constructor
    [sucrela.py]
2024-03-11 fw: add working HSPI transfer
    * Also, use CSR regs addresses from csr.h to avoid
    hard-coded addresses.
    * Increase system frequency to 30 MHz
    [main.c]
2024-03-15 uartbone: refactor backend callbacks to prepare for USB backend
    USB Bulk will be sent by strings and not byte-by-byte.
    Thus let's use a buffer/len API instead of just a byte based API.
2024-03-15 Update BSP to use new UART rx functions
2024-03-23 libuartbone: make uart_read return error code upon error
    [uartbone_linux.c]
2024-03-23 libuartbone: add support for uartbone over USB to Linux CLI
2024-03-23 fw: add support for uartbone over USB
    Host tool can now send USB commands to CH569
    to ask it to send uartbone commands to FPGA SoC.
2024-03-23 fw: allocate hspi dma buffers in RAMX via the linker instead of hard coded macros
2024-04-13 HSPI: lots of fix, cleanup and debug
    * Add lots of CSR for debug
    * Wrap all module instances with ClockDomainRenamer to allow design
    simulation in CI
    * it also allows to use a specific "HSPI" clock domain for the LA
    to reduce clock speed from 48 MHz to 4 MHz for the low speed
    prototype.
    * Add payload validation in CI
    * Add a max_packet_size CSR to control the HSPI packet size
    * Add a max_packet_number CSR to control the HSPI number of packets
    during current session
2024-04-13 Improve LA pipeline
    * Add converter and hspi packet buffer
    This allows to have smaller probe number than
    HSPI bus width.
    This also allows to run sampling and HSPI at same
    speed, because otherwise since HSPI has approx 10 bytes
    overhead (4 bytes header + 2 or 4 bytes CRC + negociation)
    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
2024-04-13 SucreLA: add support for testing mode in top level
    * testing mode inject dummy data
    * it also enables litescope inside the SoC to help debug
    on FPGA.
    * Run the LA at 4 MHz to avoid signal integrity issues with
    flying wires of the prototype.
    [sucrela.py]
2024-04-13 mcu: cleanup, remove dead code, make hspi and uartbone work
    now mcu code only acts as bridge between Host PC and FPGA for
    uartbone protocole like this:
    {PC} <=usb EP1=> {MCU} <=uart=> {FPGA [uartbone_bridge] <=> [LiteX wishbone SoC bus] <=> [LogicAnalyzer cores]}
    It also acts as bridge for sample data like this:
    {PC} <=usb EP2=> {MCU} <=HSPI=> {FPGA [LogicAnalyzer HSPI TX] <= [LA Pipeline]}
2024-04-13 libuartbone: allow to init context with libusb device handle already open
    Either call uartbone_unix_init with no libusb device handle with
    file = "usb://vendor:product/EP"
    or if you already have an open libusb handle call uartbone_unix_init
    with
    file = "usb://"
    And don't forget to set those uartbone_ctx fields:
    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
2024-09-17 hw: add hydrasucrela daughter board design files
    [FPGA_1.kicad_sch, FPGA_2.kicad_sch, FPGA_3.kicad_sch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]
2024-09-17 hw: update kicad footprints and symbols
    [FPGA_1.kicad_sch, FPGA_2.kicad_sch, FPGA_3.kicad_sch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]
2024-12-15 Update HydraSucreLA PCB
    [FPGA_2.kicad_sch, FPGA_3.kicad_sch, IO.kicad_sch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]
2024-12-16 update PCB with good connector placements
    [IO.kicad_sch, hydrasucrela.kicad_pcb]
